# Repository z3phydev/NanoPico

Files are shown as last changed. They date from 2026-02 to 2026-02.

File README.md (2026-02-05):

## NanoPico
# What is it?
Its a RP2040 Devboard ment for software apllications. It features 16 MB of flash storage and a Male USB A port
# Why did I make it?
I made it because well nothing similar exists, there are many rp2040 devboards but I just couldnt find one that was as small as posible with a male port and no gpio.
# How to use / setup
Once you recive the PCB download the 16mb.uf2 file. Plug it into your pc while shorting the F Pads. Once your PC recognises it you can stop shorting the pads. Then copy 16mb.uf2 to the drive. The drive should now disappear and reappear as "CircutPython". From here you can edit boot as you wish or do other things with python.

# 3D Model




# PCB (all layers)






# Schematic

image (6)

# BOM

|Comment |Designator |Footprint |JLC Part No.|Mft Part No. |
|---|---|---|---|---|
|100nF |C4, C5, C6, C10, C11, C12, C13, C14, C15, C16, C17, C20, C21|201 |C49062 |CL03A104KP3NNNC|
|1uF |C8, C9 |402 |C14445 |CL05A105KP5NNNC|
|10uF |C1, C2, C3 |603 |C19702 |CL10A106KP8NNNC|
|15pF |C22, C23 |603 |C1644 |CL10C150JB8NNNC|
|1 kOhm |R3, R4 |402 |C11702 |0402WGF1001TCE |
|27 Ohm |R5, R6 |402 |C25100 |0402WGF270JTCE |
|47 kOhm |R7, R8 |402 |C25563 |0402WGJ0473TCE |
|10 Ohm |R9 |603 |C22859 |0603WAF100JT5E |
|Low Voltage Dropout|U3 | SOT-23-5 |C404027 |TLV75533PDBVR  |GB
|12MHZ Crystal |Y2 |SMD2520-4P |C90603 |Q24FA20H00687  |
|Male USB A |J2 |USB A Molex 48037-2200 Horizontal|C136453 |480372100 |
|RP2040 |U1 |LQFN-56 (7x7) |C2040 |RP2040 |
|16MB Flash Storage |U2 |SOIC-8-208mil |C97521 |W25Q128JVSIQ |

## Total Price if using PCBWAY with assembly should come to around 120 GBP (160 USD)

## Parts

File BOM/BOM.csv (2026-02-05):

Item # | *Designator | *Qty | *Mfg Part # | Description / Value | *Package/Footprint | *Unit Price(1 set) | *Total | *Delivery Time | *PCBWay Note | Customer Reply | PCBWay Update
1 | C4, C5, C6, C10, C11, C12, C13, C14, C15, C16, C17, C20, C21 | 13 | CL03A104KP3NNNC | 100nF | 201 | $0.126 | $1.638
2 | C8, C9 | 2 | CL05A105KP5NNNC | 1uF | 402 | $0.655 | $1.310
3 | C1, C2, C3 | 3 | CL10A106KP8NNNC | 10uF | 603 | $0.242 | $0.726
4 | C22, C23 | 2 | CL10C150JB8NNNC | 15pF | 603 | $0.277 | $0.554
5 | R3, R4 | 2 | 0402WGF1001TCE | 1 kOhm | 402 | $0.164 | $0.328
6 | R5, R6 | 2 | 0402WGF270JTCE | 27 Ohm | 402 | $0.164 | $0.328
7 | R7, R8 | 2 | 0402WGJ0473TCE | 47 kOhm | 402 | $0.164 | $0.328
8 | R9 | 1 | 0603WAF100JT5E | 10 Ohm | 603 | $0.221 | $0.221
9 | U3 | 1 | TLV75533PDBVR | Low Voltage Dropout | SOT-23-5 | $0.282 | $0.282
10 | Y2 | 1 | Q24FA20H00687 | 12MHZ Crystal | SMD2520-4P | $0.564 | $0.564
11 | J2 | 1 | 480372100 | Male USB A | USB A Molex 48037-2200 Horizontal | $0.966 | $0.966 |  | The quoted part number is [480372100], not [48037-2200] as specified in description | No problem
12 | U1 | 1 | RP2040 | RP2040 | LQFN-56 (7x7) | $1.328 | $1.328
13 | U2 | 1 | W25Q128JVSIQ | 16MB Flash Storage | SOIC-8-208mil | $2.355 | $2.355
 |  |  |  |  |  | Component Cost | $10.93
 |  |  |  |  |  | Assembly Cost
 |  |  |  |  |  | PCB Cost
 |  |  |  |  |  | V1ÿMemberÿ1%ÿoff | $0.00
 |  |  |  |  |  | All Total 1 Sets | $10.93

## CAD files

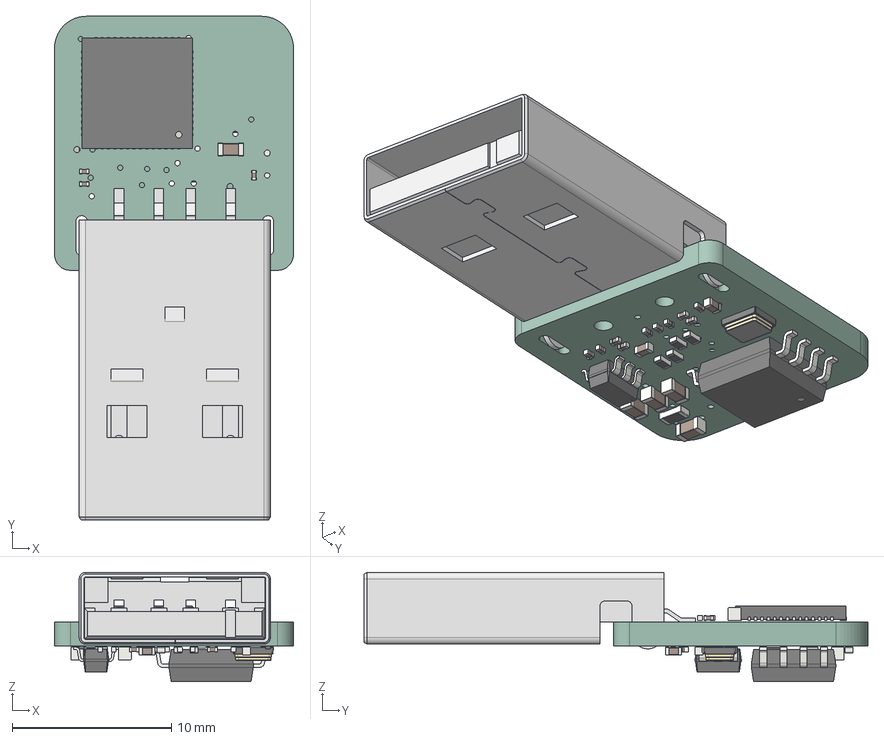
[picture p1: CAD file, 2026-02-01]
3D/Step/NanoPicoA.stp
15.0 x 31.6 x 6.86 mm
C_0201_0603Metric x 13
C_0603_1608Metric x 5
QFN-56-1EP_7x7mm_P0.4mm_EP3.2x3.2mm
SOT-23-5
SOIC-8_5.3x5.3mm_P1.27mm
R_0402_1005Metric x 6
C_0402_1005Metric x 2
Crystal_SMD_2520-4Pin_2.5x2.0mm
R_0603_1608Metric
NanoPicoA_silkscreen
NanoPicoA_PCB

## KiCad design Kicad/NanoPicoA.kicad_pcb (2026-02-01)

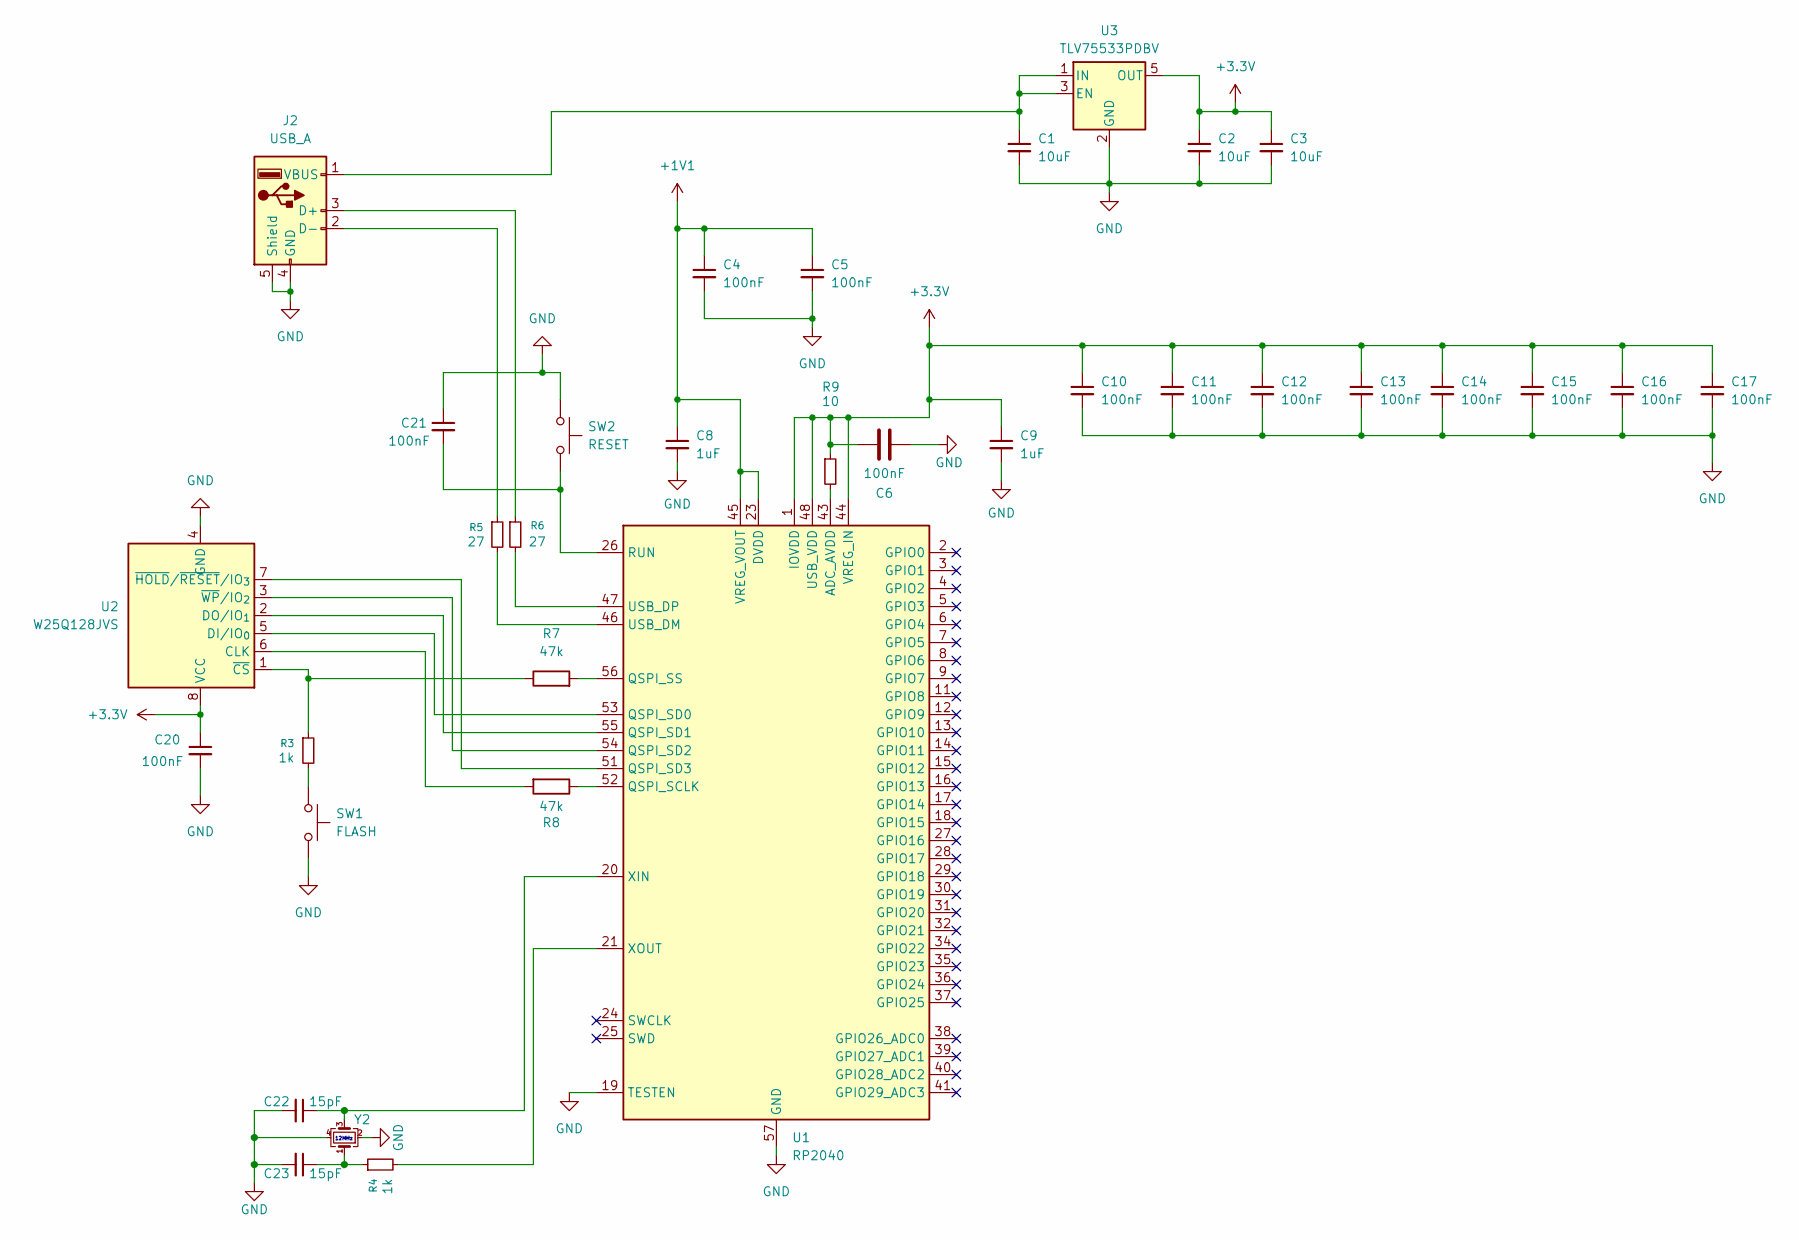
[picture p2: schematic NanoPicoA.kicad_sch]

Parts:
C1, C2, C3: 10uF; C_0603_1608Metric_Pad1.08x0.95mm_HandSolder
C4, C5, C6, C10, C11, C12, C13, C14, C15, C16, C17, C20, C21: 100nF; C_0201_0603Metric_Pad0.64x0.40mm_HandSolder
C8, C9: 1uF; C_0402_1005Metric_Pad0.74x0.62mm_HandSolder
C22, C23: 15pF; C_0603_1608Metric
J2: USB_A; USB_A_Molex_48037-2200_Horizontal
R3, R4: 1k; R_0402_1005Metric_Pad0.72x0.64mm_HandSolder
R5, R6: 27; R_0402_1005Metric_Pad0.72x0.64mm_HandSolder
R7, R8: 47k; R_0402_1005Metric_Pad0.72x0.64mm_HandSolder
R9: 10; R_0603_1608Metric_Pad0.98x0.95mm_HandSolder
SW1: FLASH; SWPAD
SW2: RESET; SWPAD
U1: RP2040; QFN-56-1EP_7x7mm_P0.4mm_EP3.2x3.2mm
U2: W25Q128JVS; SOIC-8_5.3x5.3mm_P1.27mm
U3: TLV75533PDBV; SOT-23-5
Y2: XYDBPCNANF-12MHZ; Crystal_SMD_2520-4Pin_2.5x2.0mm; LCSC C521567

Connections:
+1V1: C4.1, C5.1, C8.1, U1.23 (DVDD), U1.45 (VREG_VOUT), U1.50 (DVDD)
+3.3V: C2.1, C3.1, C6.2, C9.1, C10.1, C11.1, C12.1, C13.1, C14.1, C15.1, C16.1, C17.1, C20.1, R9.1, U1.1 (IOVDD), U1.10 (IOVDD), U1.22 (IOVDD), U1.33 (IOVDD), U1.42 (IOVDD), U1.44 (VREG_IN), U1.48 (USB_VDD), U1.49 (IOVDD), U2.8 (VCC), U3.5 (OUT)
GND: C1.2, C2.2, C3.2, C4.2, C5.2, C6.1, C8.2, C9.2, C10.2, C11.2, C12.2, C13.2, C14.2, C15.2, C16.2, C17.2, C20.2, C21.1, C22.2, C23.2, J2.4 (GND), J2.5 (Shield), SW1.2, SW2.1, U1.19 (TESTEN), U1.57 (GND), U2.4 (GND), U3.2 (GND), Y2.2, Y2.4
unnamed: C23.1, R4.1, Y2.1
unnamed: J2.3 (D+), R6.1
unnamed: J2.2 (D-), R5.1
unnamed: C1.1, J2.1 (VBUS), U3.1 (IN), U3.3 (EN)
unnamed: R3.2, SW1.1
unnamed: R9.2, U1.43 (ADC_AVDD)
unnamed: R8.1, U1.52 (QSPI_SCLK)
unnamed: U1.53 (QSPI_SD0), U2.5 (DI/IO_{0})
unnamed: U1.55 (QSPI_SD1), U2.2 (DO/IO_{1})
unnamed: U1.54 (QSPI_SD2), U2.3 (~WP/IO_{2})
unnamed: U1.51 (QSPI_SD3), U2.7 (~HOLD/~RESET/IO_{3})
unnamed: R7.2, U1.56 (QSPI_SS)
unnamed: C21.2, SW2.2, U1.26 (RUN)
unnamed: R5.2, U1.46 (USB_DM)
unnamed: R6.2, U1.47 (USB_DP)
unnamed: C22.1, U1.20 (XIN), Y2.3
unnamed: R4.2, U1.21 (XOUT)
unnamed: R8.2, U2.6 (CLK)
unnamed: R3.1, R7.1, U2.1 (~CS)

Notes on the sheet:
12MHz

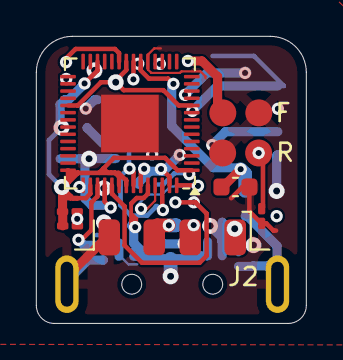
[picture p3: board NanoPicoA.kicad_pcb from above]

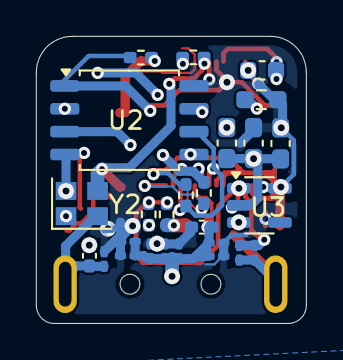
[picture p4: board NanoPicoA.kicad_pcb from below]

Board: 4 copper layers, 15.0 x 16.0 mm, 34 parts (26 on the bottom side), 22 nets.

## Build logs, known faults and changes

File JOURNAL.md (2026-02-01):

# Total Time Spent - About 23 Hours

## 1/26/2026 - Finished the Schematic - About 6 Hours  

_Time spent: 6.0h_  

Using the offical "Hardware Design with RP2040" as a reference alongside other RP2040 development board schematics. I ended up with a fairly simple custom board.

image (3)

## 1/27/2026 - Made 2 Versions (USB A Male and USB C Female) ~ 8 Hours  

_Time spent: 8.0h_  

I made 2 PCBs, one USB A version and one USB C. The usb a schematic is slightly updated as seem below.
 image (5)

The USB A version PCB is 14mm x 15mm and the total footprint is 14mm x 30.3mm 

The USB C version PCB is 14mm x 16mm whereas the total footprint is just larger at 14mm x 16.8mm



## 1/31/2026 - Finished the USB A PCB - Around 6 Hours  

_Time spent: 6.0h_  

Its like playing 3D chess. I used soo many vias and micro vias. I had to slightly increase the PCB size to 16mm x 15mm and now the overall footprint is 31.5mm x 15mm which is still really small. 

I have since decided this is the only one I'll focus on  

## 2/1/2026 - Created BOM - About 2 Hours  

_Time spent: 2.0h_  

In hindsite I proboally should have choosen the componenets before making the PCB but all is fine since im using fairly common parts. I will be using JLC Assembly so the BOM is a bit funnky. 

## 2/1/2026 5 PM - Finished Repo - About an Hour  

_Time spent: 1.0h_  

Made a Repo and made it look nice. Don't look ot close at the commits...  After looking at the prices PCBway might be cheaper but I'm just waiting for a quote. I was going to use jlc but it cost way too much in assembly cost (And I don't think I could do such precise SMD work)

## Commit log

2026-02-01 Add initial content to BOM/asf
2026-02-01 Add files via upload
    Note not all parts are present as kicad didnt have a model for them
2026-02-01 Add NanoPico project details to README
    Added detailed information about the NanoPico RP2040 Devboard, including setup instructions, 3D models, PCB layers, schematics, and BOM.
2026-02-05 PCBWAY BOM
    [BOM.csv]
2026-02-05 JLC BOM
    [JLC-BOM.csv]
